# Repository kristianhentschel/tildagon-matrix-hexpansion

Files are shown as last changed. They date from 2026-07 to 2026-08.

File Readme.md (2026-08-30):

# Matrix Hexpansion

This repository contains the firmware and hardware projects for the **Matrix Hexpansion** and the CH32V006 breakout hexpansion it is based on. This is an add-on for the EMF Camp Tildagon/Spaceagon [badge](https://tildagon.badge.emfcamp.org/).

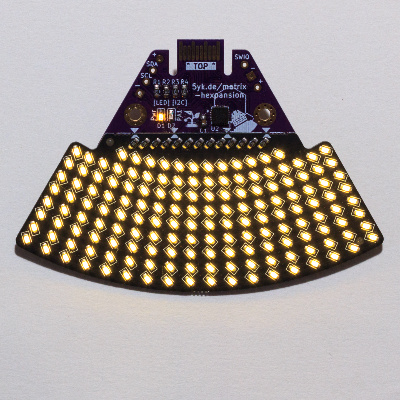
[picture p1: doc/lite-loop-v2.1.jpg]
The lite-loop LED matrix board, soldered to and placed on top of the base board. Its 156 warm-white LEDs arranged in 9 concentric arcs (1 row of 12 and 8 rows of 18) spanning 60 degrees are lit up. The hexpansion connector points to the center of the circle.


The hexpansion can be controlled with the [Matrix Hexpansion companion app](https://github.com/kristianhentschel/tildagon-matrix-hexpansion-app). The processor refreshes the LED Matrix using DMA (up to 156 LEDs with charlieplexing on its 13 available GPIO pins) and can run animated patterns or scrolling text configured by the badge over the I2C interface.

Assembled hexpansions will be available to buy from [shop.alwaysplottingsomething.com](https://shop.alwaysplottingsomething.com/category/hexpansions).

Note that the LEDs are only a single colour, and not as bright as the WS2812B/NeoPixel-style RGB LEDs seen on other hexpansions. On the other hand, you can have multiple of these plugged in without running down your battery in minutes!

## Base CH32V006 prototyping hexpansion

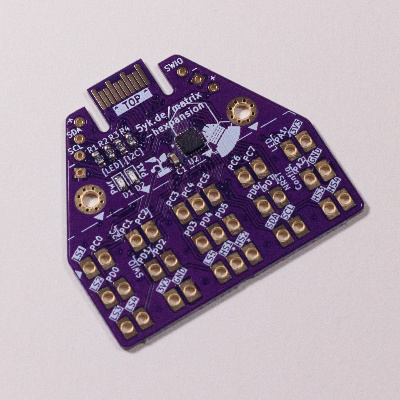
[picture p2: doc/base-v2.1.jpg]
The base board's trapezoidal top half has the hexpansion connector, a microcontroller, I2C pull-up resistors, and two status LEDs. The rectangular bottom half is a grid of three rows of rectangular pads with a large plated hole in the middle of each pad. The pads are labelled with their function in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


The common base board with the hexpansion connector must be produced with ENIG finish and holds the processor, status LEDs, configuration jumpers, and I2C pull-up resistors. It has large through hole pads for all GPIO pins and Hexpansion connector pins for a daughter board to connect to. There are also debug pads for I2C, power, and a USB programmer like the WCH LinkE.

I use the CH32V006F8U6/7 processor and program it with the [ch32fun framework](https://github.com/cnlohr/ch32fun). The CH32V003F4U6 has the same pinout and footprint, but may not have enough flash and RAM to run the matrix, control interface, and animation. If you get an assembled board from me, the processor is already programmed with a bootloader so firmware programs can be flashed from the badge without buying the dedicated USB debugger.

There is no dedicated EEPROM on the board, but the microcontroller is connected to the I2C bus and can emulate a read-only EEPROM interface if desired.

## Daughter board

Daughter boards are soldered to the base's pads, usually with SMD pads on the bottom. They can be cheaper to manufacture at low quantities (e.g. use HASL finish). The `lite-loop` board used in the Matrix Hexpansion is an example.

## Hardware

The `boards` directory contains KiCad projects and schematics for the PCBs.

* `base_v2_lite`: The base hexpansion board; with a CH32V006 co-processor and all GPIO pins and hexpansion interface pins broken out to through-hole pads.
* `lite_loop`: The 156-LED matrix display daughter board (13 pin charlie-plexing, arranged in 8 rows of 18 columns and a 9th row of 12 columns). Six instances of this make a circle surrounding the badge.

There is also a symbol library and footprints to aid in making custom daughter boards.

## Firmware

The RISC-V CH32V006 processor on the base board runs native firmware code built with the [ch32fun framework](https://github.com/cnlohr/ch32fun).

* `firmware/lite_loop` is the driver for the `lite-loop` daughter board. It maintains the LED matrix display, can run animations and scrolling text patterns, and presents an I2C interface for identifying and controlling the hexpansion from the badge.
* `firmware/bootloader_006` presents an I2C EEPROM-like interface if the `PD7` pin is pulled low during boot, so the badge can write the (non-bootloader) code flash area to replace the main program with a new firmware image.
* `firmware/blink` is a very small hello-world program that just toggles the PA1 pin attached to the status LED. It is useful when bulk provisioning or as a starting point for using the base without the lite-loop daughter board.

### Developing custom firmware

You can use the badge app to upload your own firmware program to the microcontroller on the hexpansion, for example to write your own animated patterns. To get set up you will need a few things:

1. A RISC-V toolchain, see instructions at https://github.com/cnlohr/ch32fun/wiki/Installation (building their `minichlink` and getting a USB debugger is optional as we will be using the badge to upload our firmware image).
2. A way to upload files to the badge over the USB connection, such as [mpremote](https://docs.micropython.org/en/latest/reference/mpremote.html) or [Thonny](https://thonny.org/).
3. The ["Matrix Hexpansion" app](https://apps.badge.emfcamp.org/apps/41214133), from the Tildagon app store.

Then follow these steps to upload firmware using the badge app:

1. Compile the firmware image
2. Copy the firmware image `.bin` file to the "Matrix Hexpansion" app's `assets/` folder
3. Reboop the badge
4. Open the app, and select "Firmware Upgrade", the target hexpansion slot, and your custom image.

```sh
# get the ch32fun repository
git submodule update --init --recursive

# make a copy of the lite-loop firmware to start from
cd firmware
cp -r lite_loop my_firmware

# build your firmware binary
cd my_firmware
make build

# copy the firmware image to the badge file system
mpremote cp main.bin :/apps/kristianhentschel_tildagon_matrix_hexpansion_app/assets/my_firmware.bin
```

To get started, place this code at the top of the `loop()` function in `my_firmware/main.c`:

```c
// void loop() {
  while(true) {
    for (int frame = 0; frame < 2 * LEDS_GRID_COLS; frame++) {
      for (int row = 0; row < LEDS_GRID_ROWS; row++) {
        for (int col = 0; col < LEDS_GRID_COLS; col++) {
          // Find the frame buffer index of the LED at the current row and column:
          int index = leds_grid_indices[row * LEDS_GRID_COLS + col];
          // In the array of grid indices some values are 255, because the first row only has 12 LEDs instead of 18, so skip those:
          if (index >= LEDS_COUNT) continue;
          
          // Set the LED to on or off depending on the current frame
          if (frame < LEDS_GRID_COLS) {
            frame_buffer[index] = col < frame ? 255 : 0;
          } else {
            frame_buffer[index] = col >= frame - LEDS_GRID_COLS ? 255 : 0;
          }
        }
      }

      Delay_Ms(40);
    }
  }

  // ... existing loop code, unreachable
// }
```

You may also wish to change the name in the hexpansion header; this will stop the app attempting to control it. Replace the `friendly_name` value in the hexpansion header (it must still be at most 9 characters; fill any extra slots with `0`):

```c
// static hexpansion_header_t g_hexpansion_header = {
  // ...
  // .friendly_name = {'L', 'i', 't', 'e', 'l', 'o', 'o', 'p', 0},
  .friendly_name = {'M', 'y', ' ', 'M', 'a', 't', 'r', 'i', 'x'},
// };
```

You can use the defined LED positions in [leds.h]() (using the `leds_polar_positions` and `leds_grid_indices` variables); or you could add to the list of animations, keep the name, and modify the badge app to trigger them.

Note this is all still somewhat of a prototype, for example I may change the position values to an integer representation, or come up with a system for the app to discover custom patterns to make this easier in future versions. It would also be nice to synchronise animations across multiple hexpansions.

### Bootloader and provisioning

To provision a factory-fresh processor, the bootloader must first be flashed and configured using a dedicated programmer like the WCH-LinkE and the ch32fun `minichlink` tool. We must flash the flash bootloader, configure PD7 use as GPIO rather than reset, and flash a main program. I use the `blink` program during provisioning because it is quick to build and upload; the lite_loop program is then flashed from the badge during testing. The `provision.sh` script does these steps, optionally in a loop:

```sh
./provision.sh --app blink --bootloader --loop
```
For end users, firmware updates can be applied from the badge app and a dedicated programmer is not required (but may still be helpful for debugging if writing your own firmware).

## Note on previous iteration

The base is called `v2` because the first iteration of this also had a [IS31FL3731](https://lumissil.com/assets/pdf/core/IS31FL3731_DS.pdf) LED driver, but this was found to add unnecessary cost and complexity and was never assembled or programmed properly. I suspect it would be able to drive the LED's quite a bit more brightly and consistently! In the current `v2` the current limiting resistors were moved to the daughter board and the breakout pads have a more useful generic layout, also including the hexpansion connector pins.

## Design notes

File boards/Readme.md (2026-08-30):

# Boards

* `base_v2_lite` is the base board. It has to be manufactured as a 1mm board with ENIG.
* `lite_loop` is the main "Matrix Hexpansion" LED daughter board. It can be connected to the top of the base board with solder paste and a hot air tool.

# Symbols and Footprints

* `matrix-hexpansion.kicad_sym` has schematic symbols for the base board's breakout pin array, including a version that only has the first two rows of pins as used on the `lite_loop` board.
* `matrix-hexpansion.pretty` is a footprint library including THT (used on the base) and SMD (used on the daughter boards) variations of the breakout pin array. The footprints have alignment aids on silkscreen and user layers.

# Acknowledgements

The base board is derived from the [badge-2024-hardware hexpansion template](https://github.com/emfcamp/badge-2024-hardware/tree/main/hexpansion) by kliment under CERN-OHL-P. The `hexpansion-edge-connector` symbol and footprint included with this repository for convenience are also from the same project.

# Stencils for previous version

If you want to make a stencil for your soldering kit picked up at EMF Camp 2026 (marked `v2`, `2026-05-22`), here are links to the [gerber files](https://stuff.5yk.de/20260719_lite_loop_gerber.zip) and [DXF exports](https://stuff.5yk.de/20260719_lite_loop_stencil.zip).

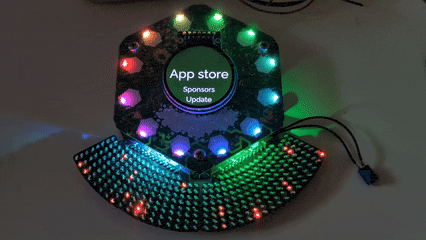
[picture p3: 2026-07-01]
doc/starfield.gif

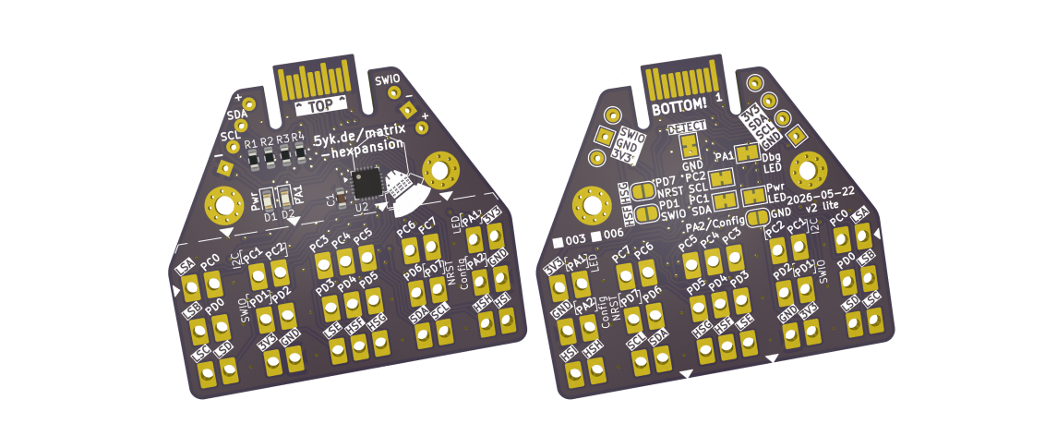
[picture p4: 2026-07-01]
doc/base-render-v2.png

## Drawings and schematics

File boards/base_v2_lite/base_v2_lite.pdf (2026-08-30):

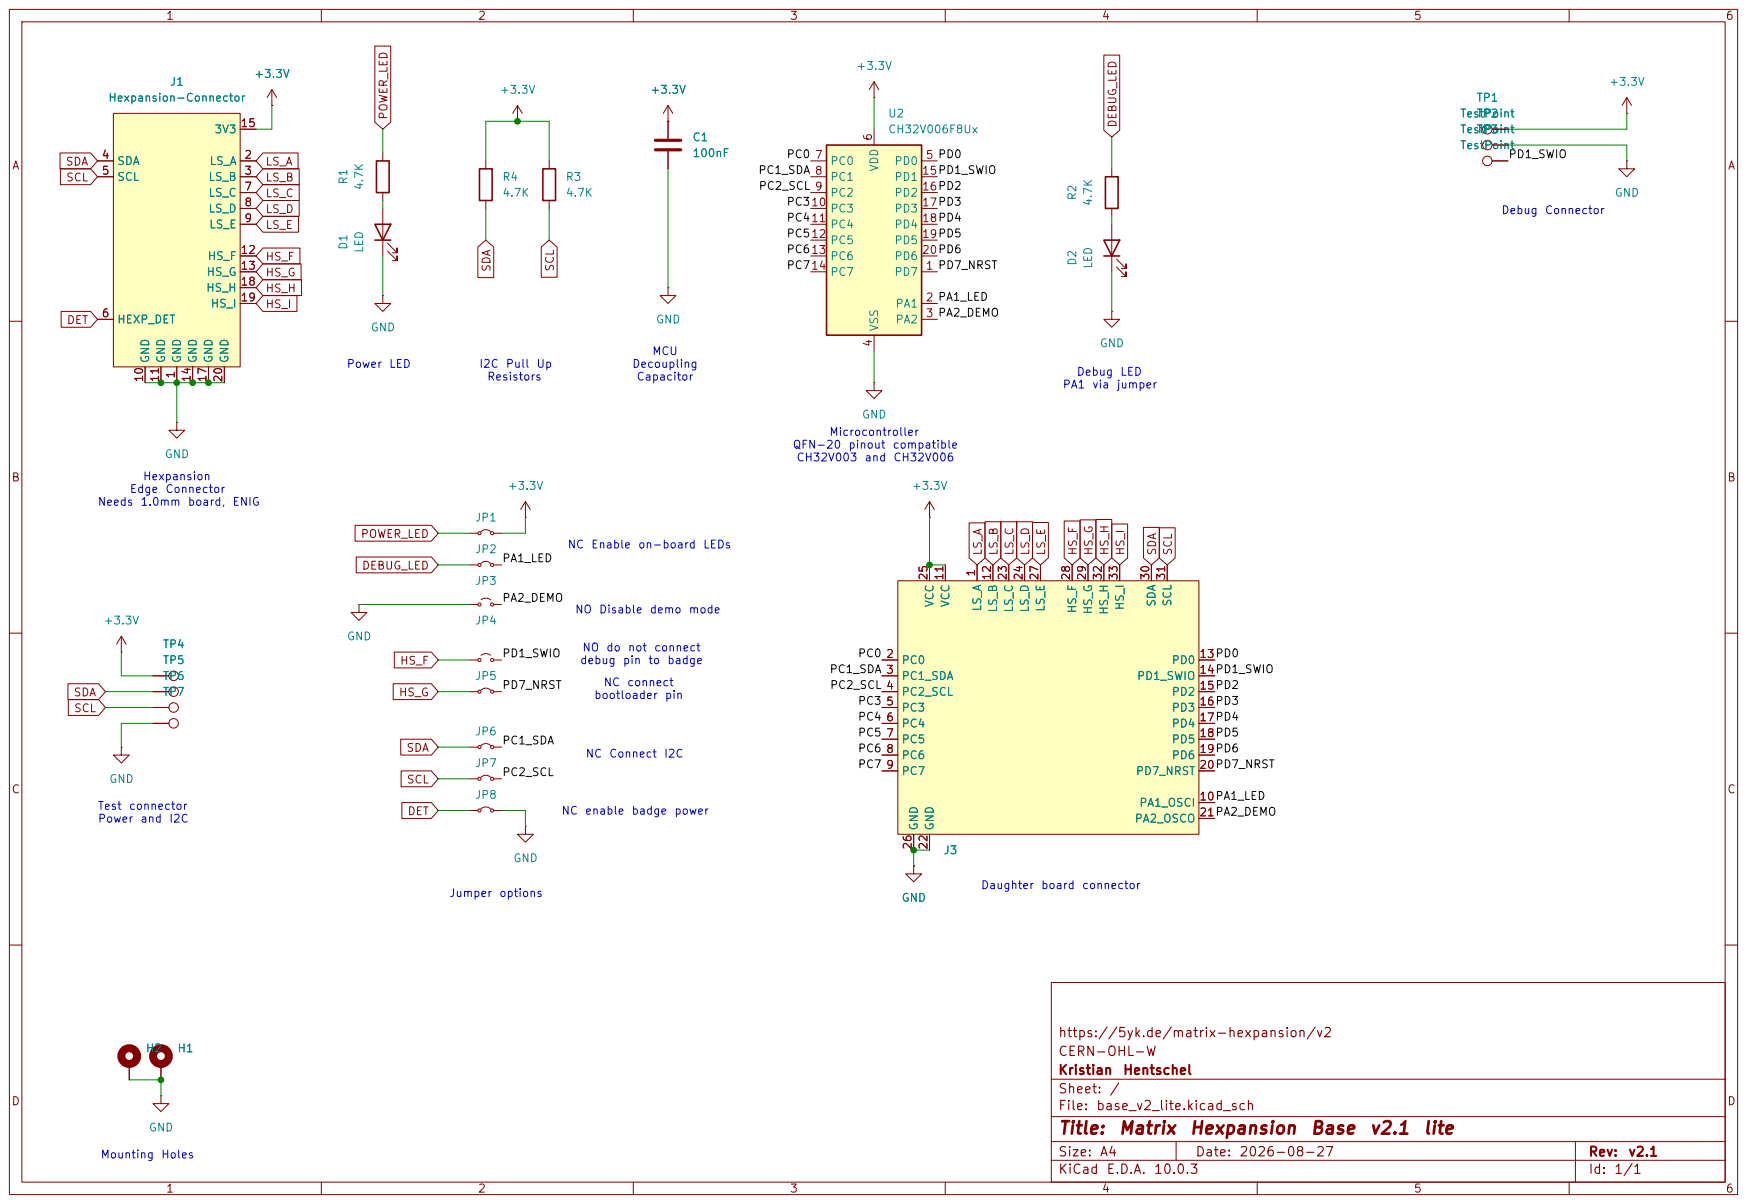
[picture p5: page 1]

Debug Connector NO Disable demo mode NC Enable on-board LEDs Hexpansion

PA1 via jumper NC Connect I2C NO do not connect debug pin to badge NC enable badge power NC connect bootloader pin Power LED

https://5yk.de/matrix-hexpansion/v2
CERN-OHL-W
Kristian Hentschel
Sheet: /
File: base_v2_lite.kicad_sch
Title: Matrix Hexpansion Base v2.1 lite

Size: A4 | Rev: v2.1
KiCad E.D.A. 10.0.3 | Id: 1/1

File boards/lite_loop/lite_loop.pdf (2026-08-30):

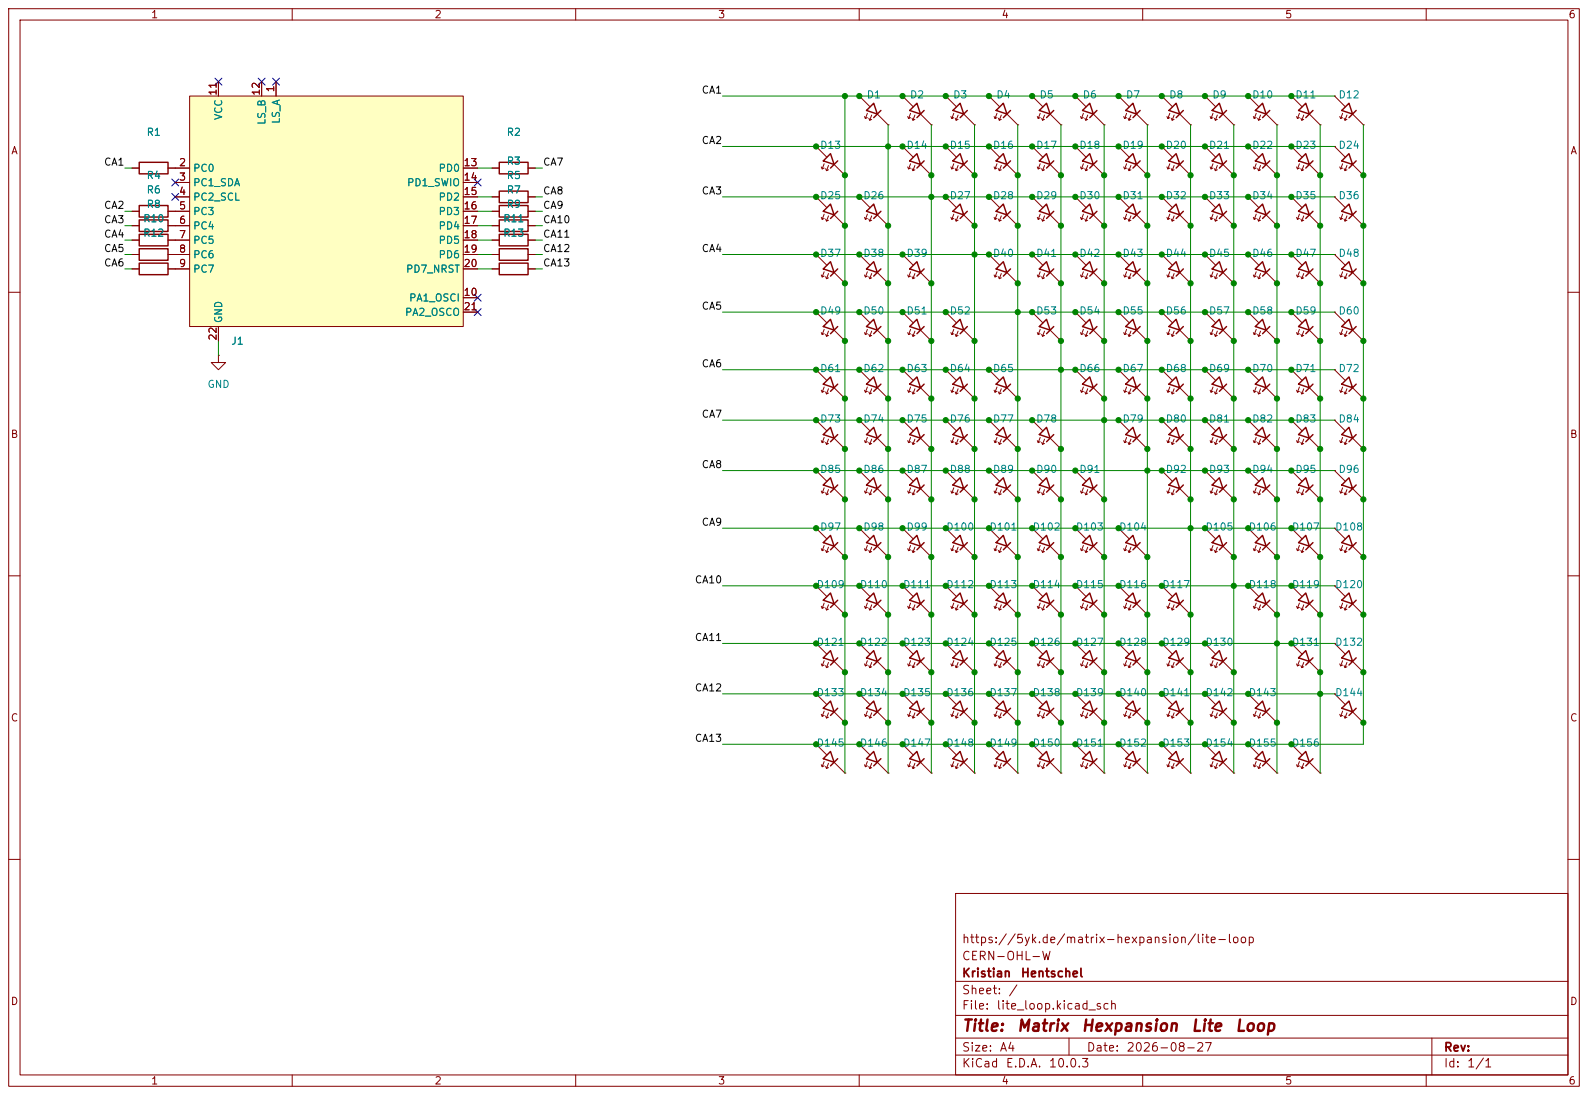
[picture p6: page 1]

https://5yk.de/matrix-hexpansion/lite-loop
CERN-OHL-W
Kristian Hentschel
Sheet: /
File: lite_loop.kicad_sch
Title: Matrix Hexpansion Lite Loop

Size: A4 | Rev:
KiCad E.D.A. 10.0.3 | Id: 1/1

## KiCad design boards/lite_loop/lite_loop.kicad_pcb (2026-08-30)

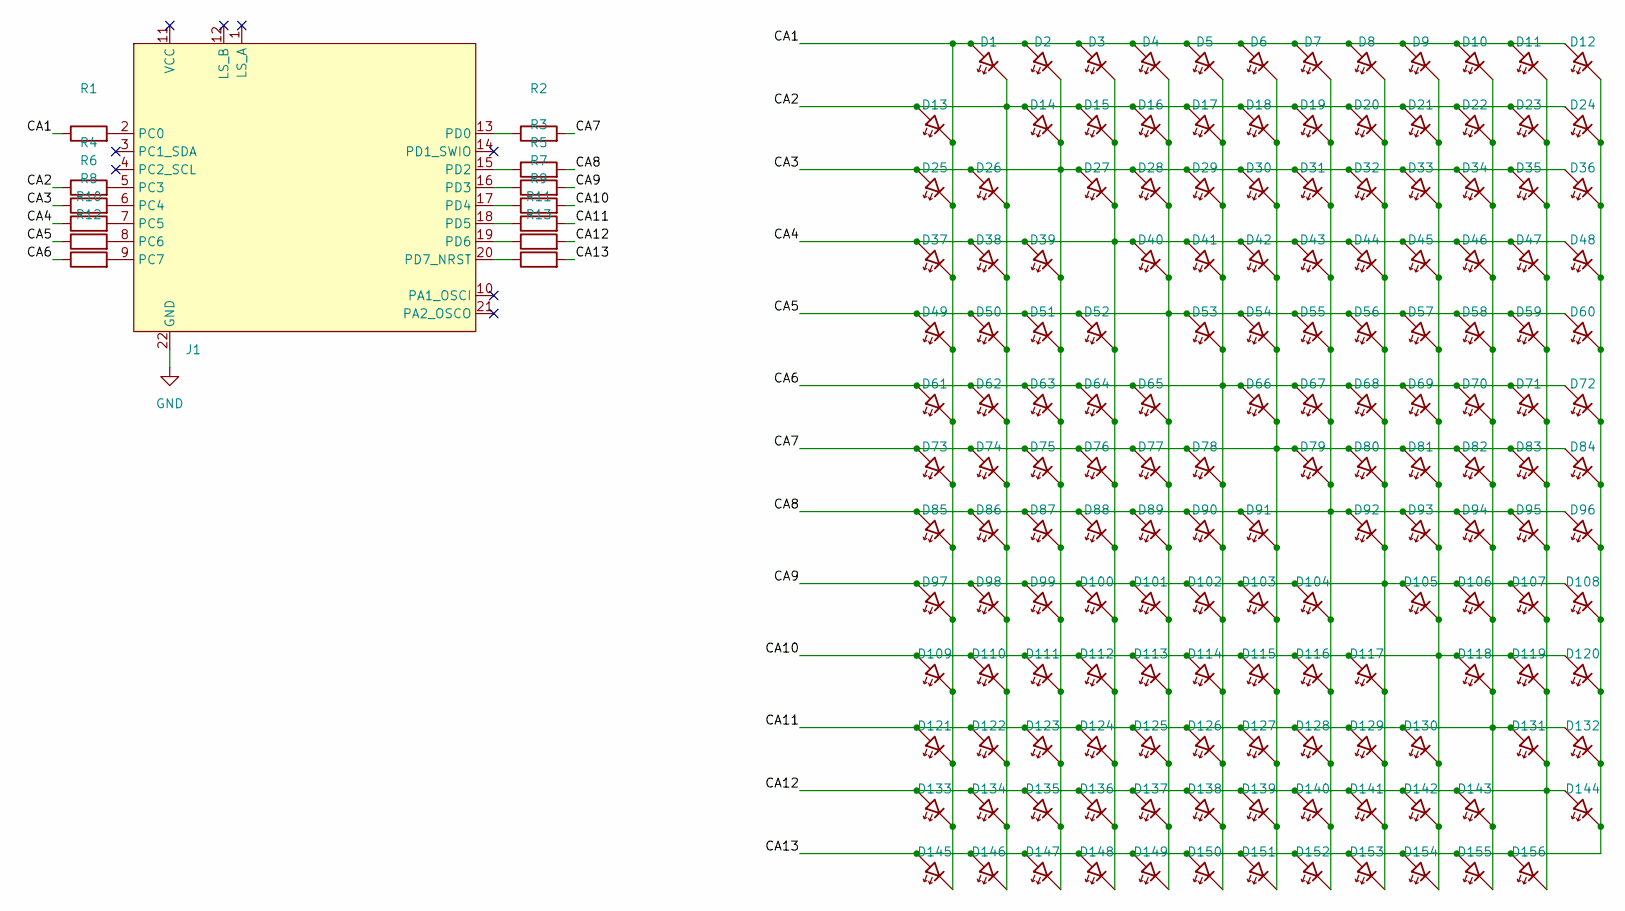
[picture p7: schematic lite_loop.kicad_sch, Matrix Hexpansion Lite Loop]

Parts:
D1, D2, D3, D4, D5, D6, D7, D8, D9, D10, D11, D12, D13, D14, D15, D16, D17, D18, D19, D20, D21, D22, D23, D24, D25, D26, D27, D28, D29, D30, D31, D32, D33, D34, D35, D36, D37, D38, D39, D40, D41, D42, D43, D44, D45, D46, D47, D48, D49, D50, D51, D52, D53, D54, D55, D56, D57, D58, D59, D60, D61, D62, D63, D64, D65, D66, D67, D68, D69, D70, D71, D72, D73, D74, D75, D76, D77, D78, D79, D80, D81, D82, D83, D84, D85, D86, D87, D88, D89, D90, D91, D92, D93, D94, D95, D96, D97, D98, D99, D100, D101, D102, D103, D104, D105, D106, D107, D108, D109, D110, D111, D112, D113, D114, D115, D116, D117, D118, D119, D120, D121, D122, D123, D124, D125, D126, D127, D128, D129, D130, D131, D132, D133, D134, D135, D136, D137, D138, D139, D140, D141, D142, D143, D144, D145, D146, D147, D148, D149, D150, D151, D152, D153, D154, D155, D156: LED; LED_0603_1608Metric
J1: matrix-hexpansion-base-v2-partial-SMD
R1, R2, R3, R4, R5, R6, R7, R8, R9, R10, R11, R12, R13: 100R; R_0603_1608Metric

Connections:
/CA1: D1.2 (A), D2.2 (A), D3.2 (A), D4.2 (A), D5.2 (A), D6.2 (A), D7.2 (A), D8.2 (A), D9.2 (A), D10.2 (A), D11.2 (A), D12.2 (A), D13.1 (K), D25.1 (K), D37.1 (K), D49.1 (K), D61.1 (K), D73.1 (K), D85.1 (K), D97.1 (K), D109.1 (K), D121.1 (K), D133.1 (K), D145.1 (K), R1.1
/CA2: D1.1 (K), D13.2 (A), D14.2 (A), D15.2 (A), D16.2 (A), D17.2 (A), D18.2 (A), D19.2 (A), D20.2 (A), D21.2 (A), D22.2 (A), D23.2 (A), D24.2 (A), D26.1 (K), D38.1 (K), D50.1 (K), D62.1 (K), D74.1 (K), D86.1 (K), D98.1 (K), D110.1 (K), D122.1 (K), D134.1 (K), D146.1 (K), R4.1
/CA3: D2.1 (K), D14.1 (K), D25.2 (A), D26.2 (A), D27.2 (A), D28.2 (A), D29.2 (A), D30.2 (A), D31.2 (A), D32.2 (A), D33.2 (A), D34.2 (A), D35.2 (A), D36.2 (A), D39.1 (K), D51.1 (K), D63.1 (K), D75.1 (K), D87.1 (K), D99.1 (K), D111.1 (K), D123.1 (K), D135.1 (K), D147.1 (K), R6.1
/CA4: D3.1 (K), D15.1 (K), D27.1 (K), D37.2 (A), D38.2 (A), D39.2 (A), D40.2 (A), D41.2 (A), D42.2 (A), D43.2 (A), D44.2 (A), D45.2 (A), D46.2 (A), D47.2 (A), D48.2 (A), D52.1 (K), D64.1 (K), D76.1 (K), D88.1 (K), D100.1 (K), D112.1 (K), D124.1 (K), D136.1 (K), D148.1 (K), R8.1
/CA5: D4.1 (K), D16.1 (K), D28.1 (K), D40.1 (K), D49.2 (A), D50.2 (A), D51.2 (A), D52.2 (A), D53.2 (A), D54.2 (A), D55.2 (A), D56.2 (A), D57.2 (A), D58.2 (A), D59.2 (A), D60.2 (A), D65.1 (K), D77.1 (K), D89.1 (K), D101.1 (K), D113.1 (K), D125.1 (K), D137.1 (K), D149.1 (K), R10.1
/CA6: D5.1 (K), D17.1 (K), D29.1 (K), D41.1 (K), D53.1 (K), D61.2 (A), D62.2 (A), D63.2 (A), D64.2 (A), D65.2 (A), D66.2 (A), D67.2 (A), D68.2 (A), D69.2 (A), D70.2 (A), D71.2 (A), D72.2 (A), D78.1 (K), D90.1 (K), D102.1 (K), D114.1 (K), D126.1 (K), D138.1 (K), D150.1 (K), R12.1
/CA7: D6.1 (K), D18.1 (K), D30.1 (K), D42.1 (K), D54.1 (K), D66.1 (K), D73.2 (A), D74.2 (A), D75.2 (A), D76.2 (A), D77.2 (A), D78.2 (A), D79.2 (A), D80.2 (A), D81.2 (A), D82.2 (A), D83.2 (A), D84.2 (A), D91.1 (K), D103.1 (K), D115.1 (K), D127.1 (K), D139.1 (K), D151.1 (K), R2.2
/CA8: D7.1 (K), D19.1 (K), D31.1 (K), D43.1 (K), D55.1 (K), D67.1 (K), D79.1 (K), D85.2 (A), D86.2 (A), D87.2 (A), D88.2 (A), D89.2 (A), D90.2 (A), D91.2 (A), D92.2 (A), D93.2 (A), D94.2 (A), D95.2 (A), D96.2 (A), D104.1 (K), D116.1 (K), D128.1 (K), D140.1 (K), D152.1 (K), R3.2
/CA9: D8.1 (K), D20.1 (K), D32.1 (K), D44.1 (K), D56.1 (K), D68.1 (K), D80.1 (K), D92.1 (K), D97.2 (A), D98.2 (A), D99.2 (A), D100.2 (A), D101.2 (A), D102.2 (A), D103.2 (A), D104.2 (A), D105.2 (A), D106.2 (A), D107.2 (A), D108.2 (A), D117.1 (K), D129.1 (K), D141.1 (K), D153.1 (K), R5.2
/CA10: D9.1 (K), D21.1 (K), D33.1 (K), D45.1 (K), D57.1 (K), D69.1 (K), D81.1 (K), D93.1 (K), D105.1 (K), D109.2 (A), D110.2 (A), D111.2 (A), D112.2 (A), D113.2 (A), D114.2 (A), D115.2 (A), D116.2 (A), D117.2 (A), D118.2 (A), D119.2 (A), D120.2 (A), D130.1 (K), D142.1 (K), D154.1 (K), R7.2
/CA11: D10.1 (K), D22.1 (K), D34.1 (K), D46.1 (K), D58.1 (K), D70.1 (K), D82.1 (K), D94.1 (K), D106.1 (K), D118.1 (K), D121.2 (A), D122.2 (A), D123.2 (A), D124.2 (A), D125.2 (A), D126.2 (A), D127.2 (A), D128.2 (A), D129.2 (A), D130.2 (A), D131.2 (A), D132.2 (A), D143.1 (K), D155.1 (K), R9.2
/CA12: D11.1 (K), D23.1 (K), D35.1 (K), D47.1 (K), D59.1 (K), D71.1 (K), D83.1 (K), D95.1 (K), D107.1 (K), D119.1 (K), D131.1 (K), D133.2 (A), D134.2 (A), D135.2 (A), D136.2 (A), D137.2 (A), D138.2 (A), D139.2 (A), D140.2 (A), D141.2 (A), D142.2 (A), D143.2 (A), D144.2 (A), D156.1 (K), R11.2
/CA13: D12.1 (K), D24.1 (K), D36.1 (K), D48.1 (K), D60.1 (K), D72.1 (K), D84.1 (K), D96.1 (K), D108.1 (K), D120.1 (K), D132.1 (K), D144.1 (K), D145.2 (A), D146.2 (A), D147.2 (A), D148.2 (A), D149.2 (A), D150.2 (A), D151.2 (A), D152.2 (A), D153.2 (A), D154.2 (A), D155.2 (A), D156.2 (A), R13.2
GND: J1.22 (GND)
unnamed: J1.2 (PC0), R1.2
unnamed: J1.5 (PC3), R4.2
unnamed: J1.6 (PC4), R6.2
unnamed: J1.7 (PC5), R8.2
unnamed: J1.8 (PC6), R10.2
unnamed: J1.9 (PC7), R12.2
unnamed: J1.13 (PD0), R2.1
unnamed: J1.15 (PD2), R3.1
unnamed: J1.16 (PD3), R5.1
unnamed: J1.17 (PD4), R7.1
unnamed: J1.18 (PD5), R9.1
unnamed: J1.19 (PD6), R11.1
unnamed: J1.20 (PD7_NRST), R13.1

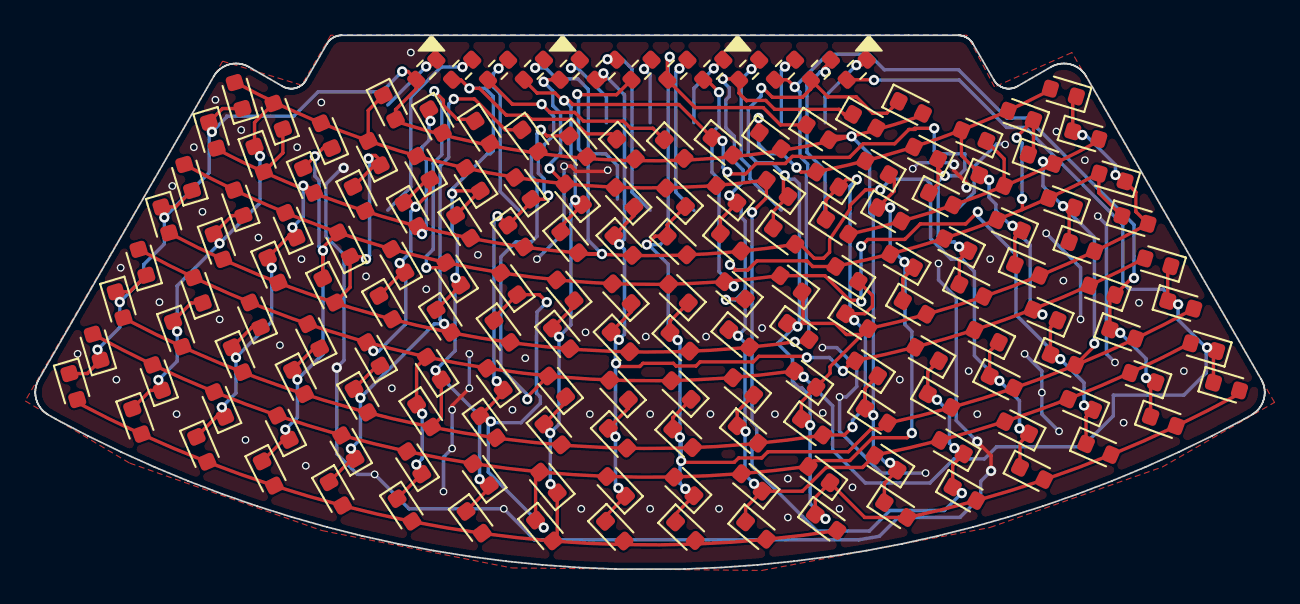
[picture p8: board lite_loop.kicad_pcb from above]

Board: 2 copper layers, 71.4 x 31.0 mm, 170 parts (0 on the bottom side), 26 nets.

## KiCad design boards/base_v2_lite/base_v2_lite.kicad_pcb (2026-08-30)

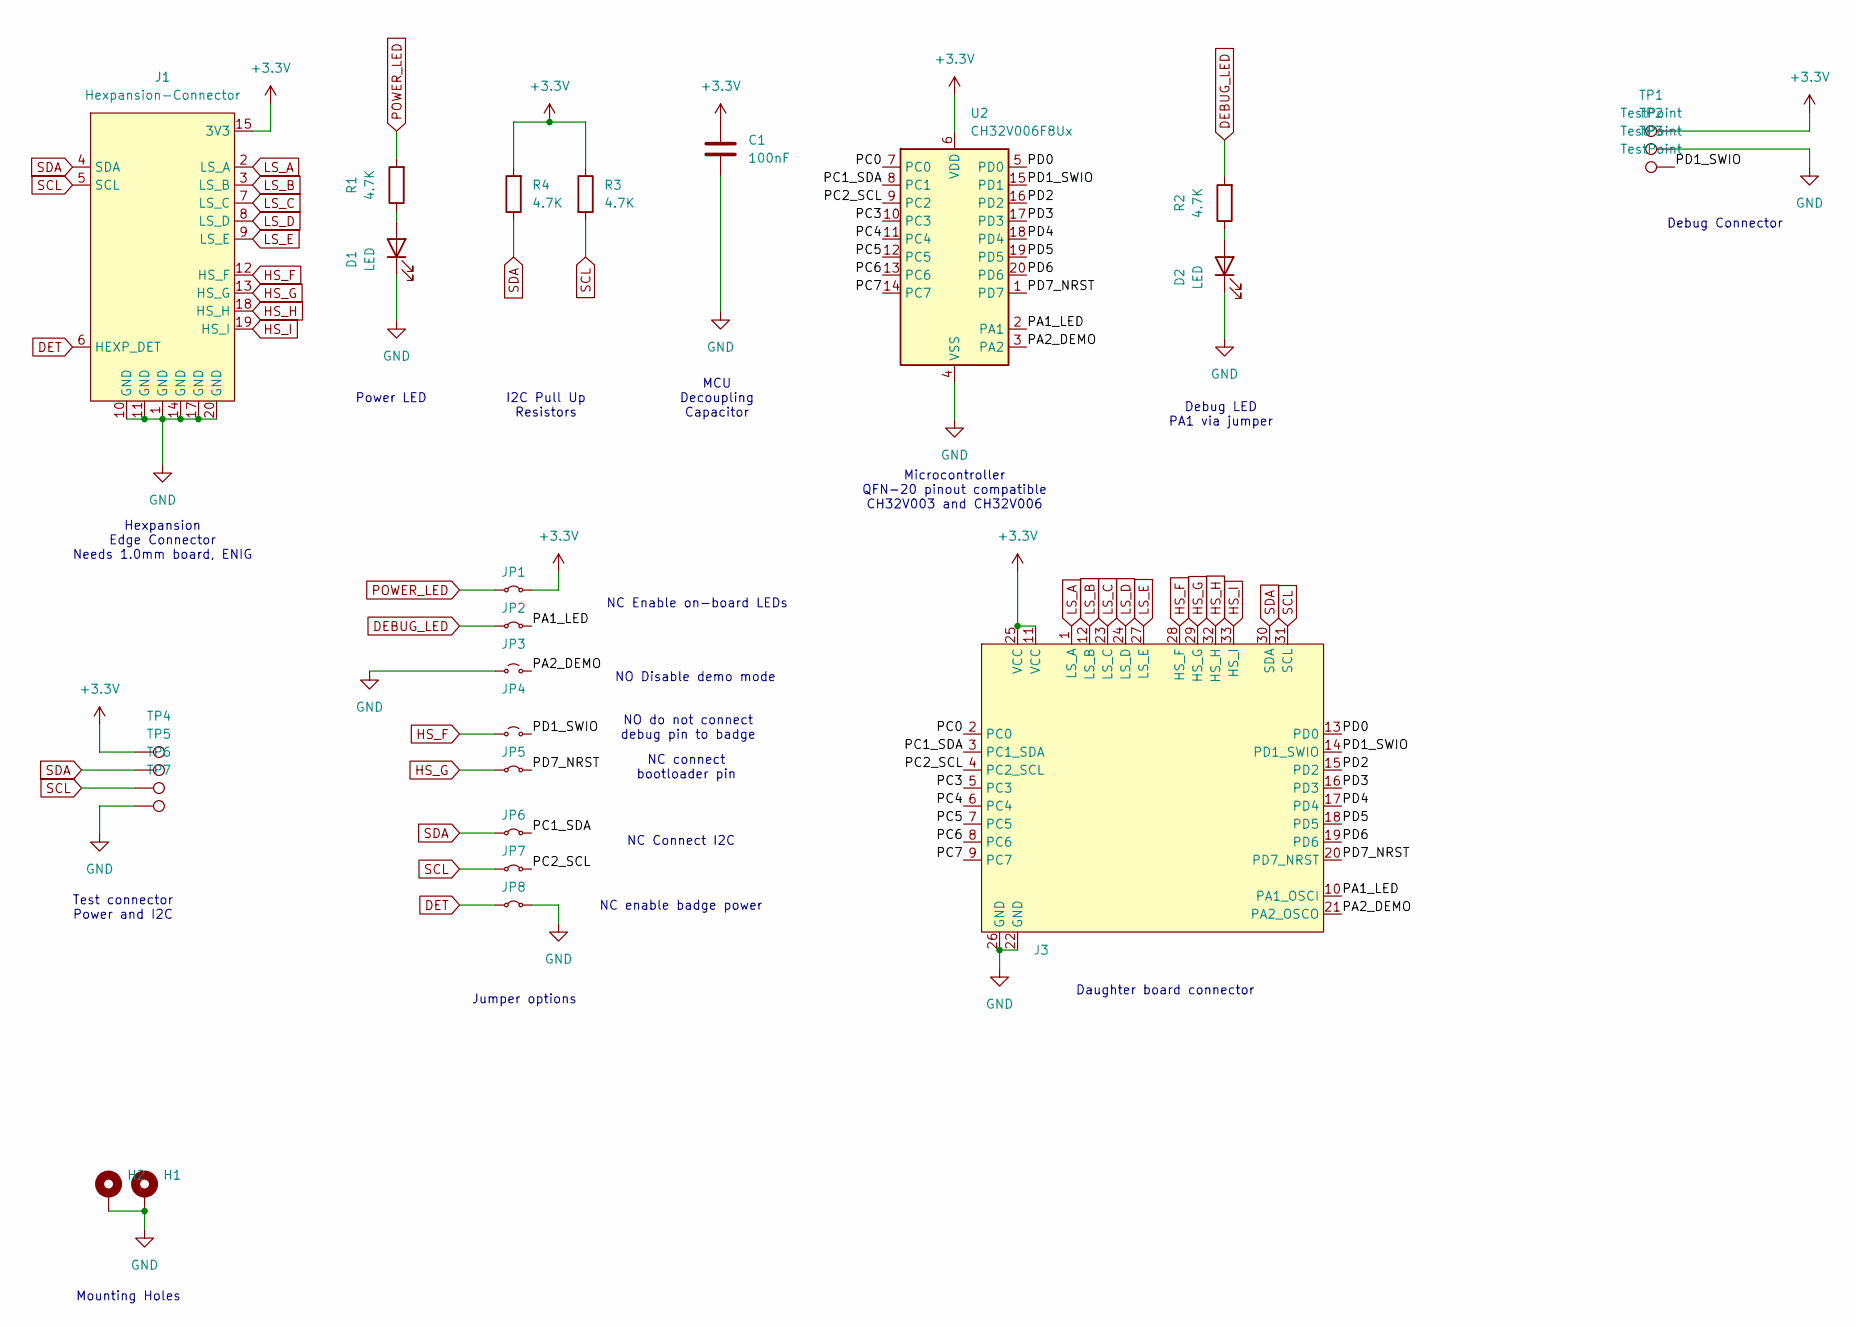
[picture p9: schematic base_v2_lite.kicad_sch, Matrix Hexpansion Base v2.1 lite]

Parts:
C1: 100nF; C_0603_1608Metric
D1, D2: LED; LED_0603_1608Metric
H1, H2: MountingHole_Pad; MountingHole_2.2mm_M2_Pad_Via
J1: Hexpansion-Connector; hexpansion-edge-connector
J3: matrix-hexpansion-base-v2-THT
JP1, JP2, JP5, JP6, JP7, JP8: Jumper_2_Small_Bridged; SolderJumper-2_P1.3mm_Bridged_Pad1.0x1.5mm
JP3, JP4: Jumper_2_Small_Open; SolderJumper-2_P1.3mm_Open_RoundedPad1.0x1.5mm
R1, R2, R3, R4: 4.7K; R_0603_1608Metric
TP1, TP3, TP4, TP5, TP6: TestPoint; TestPoint_THTPad_D1.5mm_Drill0.7mm
TP2, TP7: TestPoint; TestPoint_THTPad_1.5x1.5mm_Drill0.7mm
U2: CH32V006F8Ux; QFN-20-1EP_3x3mm_P0.4mm_EP1.65x1.65mm

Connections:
+3.3V: C1.1, J1.15 (3V3), J1.16 (3V3), J3.11 (VCC), J3.25 (VCC), JP1.2 (B), R3.1, R4.2, TP1.1 (1_1), TP4.1 (1_1), U2.6 (VDD)
/PA1_LED: J3.10 (PA1_OSCI), JP2.2 (B), U2.2 (PA1)
/PA2_DEMO: J3.21 (PA2_OSCO), JP3.2 (B), U2.3 (PA2)
/PC0: J3.2 (PC0), U2.7 (PC0)
/PC1_SDA: J3.3 (PC1_SDA), JP6.2 (B), U2.8 (PC1)
/PC2_SCL: J3.4 (PC2_SCL), JP7.2 (B), U2.9 (PC2)
/PC3: J3.5 (PC3), U2.10 (PC3)
/PC4: J3.6 (PC4), U2.11 (PC4)
/PC5: J3.7 (PC5), U2.12 (PC5)
/PC6: J3.8 (PC6), U2.13 (PC6)
/PC7: J3.9 (PC7), U2.14 (PC7)
/PD0: J3.13 (PD0), U2.5 (PD0)
/PD1_SWIO: J3.14 (PD1_SWIO), JP4.2 (B), TP3.1 (1_1), U2.15 (PD1)
/PD2: J3.15 (PD2), U2.16 (PD2)
/PD3: J3.16 (PD3), U2.17 (PD3)
/PD4: J3.17 (PD4), U2.18 (PD4)
/PD5: J3.18 (PD5), U2.19 (PD5)
/PD6: J3.19 (PD6), U2.20 (PD6)
/PD7_NRST: J3.20 (PD7_NRST), JP5.2 (B), U2.1 (PD7)
DEBUG_LED: JP2.1 (A), R2.2
DET: J1.6 (HEXP_DET), JP8.1 (A)
GND: C1.2, D1.1 (K), D2.1 (K), H1.1 (1_1), H2.1 (1_1), J1.1 (GND), J1.10 (GND), J1.11 (GND), J1.14 (GND), J1.17 (GND), J1.20 (GND), J3.22 (GND), J3.26 (GND), JP3.1 (A), JP8.2 (B), TP2.1 (1_1), TP7.1 (1_1), U2.4 (VSS), U2.21 (VSS)
HS_F: J1.12 (HS_F), J3.28 (HS_F), JP4.1 (A)
HS_G: J1.13 (HS_G), J3.29 (HS_G), JP5.1 (A)
HS_H: J1.18 (HS_H), J3.32 (HS_H)
HS_I: J1.19 (HS_I), J3.33 (HS_I)
LS_A: J1.2 (LS_A), J3.1 (LS_A)
LS_B: J1.3 (LS_B), J3.12 (LS_B)
LS_C: J1.7 (LS_C), J3.23 (LS_C)
LS_D: J1.8 (LS_D), J3.24 (LS_D)
LS_E: J1.9 (LS_E), J3.27 (LS_E)
unnamed: D1.2 (A), R1.1
unnamed: D2.2 (A), R2.1
POWER_LED: JP1.1 (A), R1.2
SCL: J1.5 (SCL), J3.31 (SCL), JP7.1 (A), R3.2, TP6.1 (1_1)
SDA: J1.4 (SDA), J3.30 (SDA), JP6.1 (A), R4.1, TP5.1 (1_1)

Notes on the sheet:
Hexpansion Edge Connector Needs 1.0mm board, ENIG
Mounting Holes
NO Disable demo mode
NC Enable on-board LEDs
MCU Decoupling Capacitor
Test connector Power and I2C
NC connect bootloader pin
Microcontroller QFN-20 pinout compatible CH32V003 and CH32V006
Debug LED PA1 via jumper
NC enable badge power
I2C Pull Up Resistors
Jumper options
Power LED
Daughter board connector
Debug Connector
NO do not connect debug pin to badge
NC Connect I2C

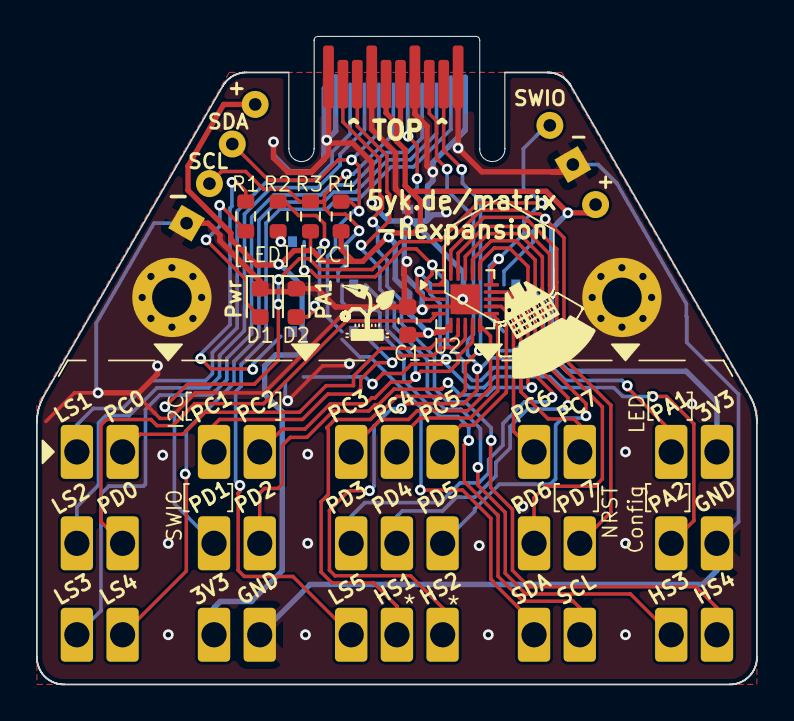
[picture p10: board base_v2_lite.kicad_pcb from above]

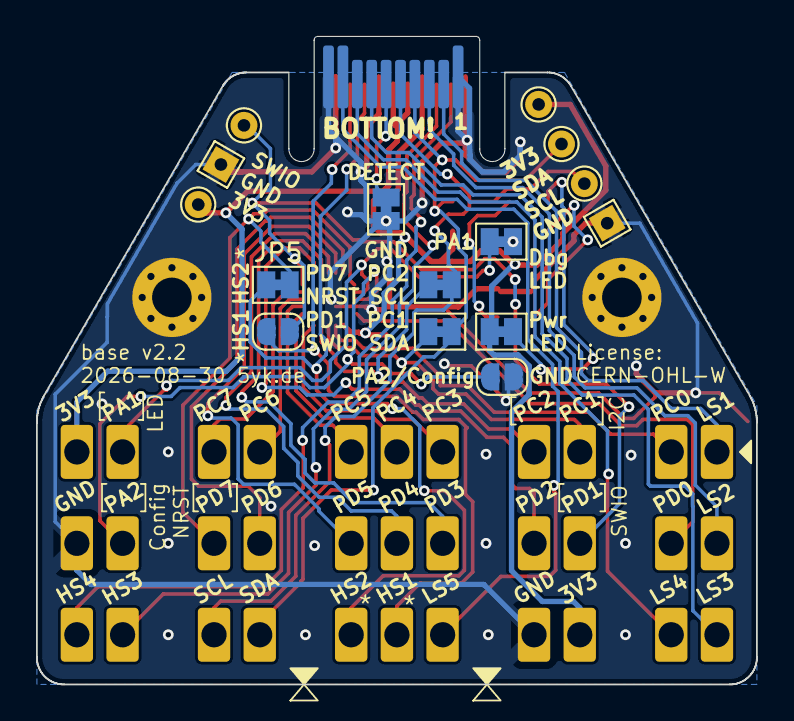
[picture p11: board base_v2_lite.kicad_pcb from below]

Board: 2 copper layers, 40.0 x 36.0 mm, 27 parts (15 on the bottom side), 36 nets.

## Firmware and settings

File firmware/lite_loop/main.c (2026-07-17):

#include "ch32fun.h"
#include <stdio.h>
#include "../shared/matrix.h"
#include "../shared/debug_printf.h"
#include "../shared/hexpansion_header.h"
#include "../shared/i2c_again.h"
#include "../shared/core_registers.h"
#include "leds.h"
#include "animations/level.h"
#include "animations/starfield.h"
#include "animations/text.h"

// #define DEBUG_BLINK

void loop() __attribute__((section(".srodata")));

uint32_t count;
matrix_pwm_t frame_buffer[MATRIX_NUM_LEDS];

static hexpansion_header_t g_hexpansion_header = {
  .magic = {'T', 'H', 'E', 'X'},
  .manifest_version = {'2', '0', '2', '4'},
  .filesystem_info = {
    .offset = 32, // offset from start of eeprom, must be multiple of page size
    .page_size = 32, // emulated eeprom page size (not littlefs block size I think)
    .total_size = 0, // emulated space, reads past fs will return zero
  },
  .vendor_id = 0xCAFE, // "misc hexpansions" from https://badge.emfcamp.org/Tildagon/UHB-IF/Uncontrolled_IDs
  .product_id = 0x54E1,
  .unique_id = 0x0000,
  .friendly_name = {'L', 'i', 't', 'e', 'l', 'o', 'o', 'p', 0},
};

volatile core_registers_t g_core_registers = {
  .core_registers_version = CORE_REGISTERS_VERSION,
};
i2c_page_definition_t g_page_definitions[] = {
  {.page_address = 0, .data = (uint8_t *)&g_core_registers, .data_size = sizeof(g_core_registers)},
};

static const i2c_config_t g_i2c_config = {
  .primary_address = 0x20,
  .primary_num_pages = 1,
  .primary_page_definitions = g_page_definitions,

  .secondary_address = 0x50, // EEPROM on 0x50 (expected fixed address by companion app)
  .secondary_header =  &g_hexpansion_header,
  .secondary_fs = NULL,
  .secondary_fs_size = 0,
};

int main()
{
  SystemInit();
  Delay_Ms(50);

  funGpioInitAll();
  funPinMode(PA1, FUN_OUTPUT);
  funPinMode(PC1, GPIO_CFGLR_OUT_10Mhz_AF_OD); // SDA
  funPinMode(PC2, GPIO_CFGLR_OUT_10Mhz_AF_OD); // SCL

  funDigitalWrite(PA1, FUN_LOW);

  g_hexpansion_header.unique_id = ESIG->UNIID1 ^ ESIG->UNIID2 ^ ESIG->UNIID3 & 0xFFFF;
  hexpansion_header_fill_checksum(&g_hexpansion_header);

  i2c_setup(&g_i2c_config);

  matrix_setup(frame_buffer);

  g_core_registers.animation_type = 2;
  loop();
}

void loop() {
  int i = 0;
  while(1) {
    if (g_core_registers.direct_control_options != 0) {
      switch (g_core_registers.direct_control_options & CORE_REGISTERS_DIRECT_CONTROL_TYPE) {
        case CORE_REGISTERS_DIRECT_CONTROL_TYPE_CONST:
          // Constant mode: all LEDs set to the same PWM value (that of the first byte)
          for (uint8_t j = 0; j < MATRIX_NUM_LEDS; j++) {
            frame_buffer[j] = g_core_registers.direct_control_data[0];
          }
          break;
        case CORE_REGISTERS_DIRECT_CONTROL_TYPE_BIT:
          // Bit mode: unpack each bit in a 20 byte array to turn one LED fully on or off
          for (uint8_t j = 0; j < 20; j++) {
            for (uint8_t k = 0; k < 8; k++) {
              if (j * 8 + k < MATRIX_NUM_LEDS) {
                frame_buffer[j * 8 + k] = (g_core_registers.direct_control_data[j] & (0x01 << (7 - k))) ? 255 : 0;
              }
            }
          }
          break;
        case CORE_REGISTERS_DIRECT_CONTROL_TYPE_BYTE:
          // Byte morde: each settings byte controls the PWM level of one LED (1:1 mapping)
          for (uint8_t j = 0; j < MATRIX_NUM_LEDS; j++) {
            frame_buffer[j] = g_core_registers.direct_control_data[j];
          }
          break;
      }
    } else if (g_core_registers.animation_type == 1) {
      animation_level(&g_core_registers, frame_buffer);
    } else if (g_core_registers.animation_type == 2) {
      animation_starfield(&g_core_registers, frame_buffer);
    } else if (g_core_registers.animation_type == 3) {
      animation_text(&g_core_registers, frame_buffer);
    } else {
      // default test pattern (fill in wiring order)
      for (uint8_t j = 0; j < MATRIX_NUM_LEDS; j++) {
        frame_buffer[j] = j < i ? 255 : 4;
      }

      i = (i + 1) % (MATRIX_NUM_LEDS + 1);
      Delay_Ms(16);
      if (i == 0) {
        Delay_Ms(500);
      }
    }

    // Liveness indicator
    #ifdef DEBUG_BLINK
    static uint32_t _last_blink_tick = 0;
    if (TimeElapsed32u(SysTick->CNT, _last_blink_tick) > Ticks_from_Ms(100)) {
      funDigitalWrite(PA1, !funDigitalRead(PA1));
      _last_blink_tick = SysTick->CNT;
    }
    #endif
  }
}

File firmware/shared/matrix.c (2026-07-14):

#include "./matrix.h"

// DMA and timer configuration based on the ch32fun dma_gpio example.

volatile const uint8_t MATRIX_GPIOC_PINS[MATRIX_NUM_GPIOC_PINS] = { 
  MATRIX_GPIOC_0,
  MATRIX_GPIOC_1,
  MATRIX_GPIOC_2,
  MATRIX_GPIOC_3,
  #ifdef MATRIX_GPIOC_4
  MATRIX_GPIOC_4,
  #endif
  #ifdef MATRIX_GPIOC_5
  MATRIX_GPIOC_5,
  #endif
  #ifdef MATRIX_GPIOC_6
  MATRIX_GPIOC_6,
  #endif
  #ifdef MATRIX_GPIOC_7
  MATRIX_GPIOC_7,
  #endif
};
volatile const uint8_t MATRIX_GPIOD_PINS[MATRIX_NUM_GPIOD_PINS] = {
  MATRIX_GPIOD_0,
  MATRIX_GPIOD_1,
  MATRIX_GPIOD_2,
  MATRIX_GPIOD_3,
  #ifdef MATRIX_GPIOD_4
  MATRIX_GPIOD_4,
  #endif
  #ifdef MATRIX_GPIOD_5
  MATRIX_GPIOD_5,
  #endif
  #ifdef MATRIX_GPIOD_6
  MATRIX_GPIOD_6,
  #endif
  #ifdef MATRIX_GPIOD_7
  MATRIX_GPIOD_7,
  #endif
};

// Reference to the currently active frame buffer, expected to hold a PWM value for each LED.
static volatile matrix_pwm_t *current_frame_buffer = 0;
static volatile matrix_pwm_t *next_frame_buffer = 0;
static volatile uint8_t buffer_swap_flag = 0;

// Define buffers to hold the PWM signals to output to the GPIO ports
#define BUF_SIZE MATRIX_BUF_SIZE
#define HALF_BUF_SIZE (BUF_SIZE / 2)

static volatile uint8_t PWM_BUF_GPIOC[BUF_SIZE];
static volatile uint8_t PWM_BUF_GPIOD[BUF_SIZE];

// For each column, for each row pin, store the index into the frame buffer
#ifdef MATRIX_INDEPENDENT_PORTS
  static volatile uint8_t ROWS_GPIOC[MATRIX_NUM_GPIOC_PINS][MATRIX_NUM_GPIOC_PINS];
  static volatile uint8_t ROWS_GPIOD[MATRIX_NUM_GPIOD_PINS][MATRIX_NUM_GPIOD_PINS];
#else
  static volatile uint8_t ROWS_GPIOC[MATRIX_NUM_PINS][MATRIX_NUM_GPIOC_PINS];
  static volatile uint8_t ROWS_GPIOD[MATRIX_NUM_PINS][MATRIX_NUM_GPIOD_PINS];
#endif

#ifdef MATRIX_EXTRA_LED_GPIOD
  // Holds the frame buffer index for the extra LED
  static volatile uint8_t EXTRA_GPIOD;
#endif

static volatile uint32_t RESET_GPIOC_CFGLR;
static volatile uint32_t RESET_GPIOD_CFGLR;

void matrix_setup(volatile matrix_pwm_t *frame_buffer) {
  // Keep a reference to the current frame buffer
  if (current_frame_buffer != 0) {
    // already initialised
    matrix_swap_buffer(frame_buffer);
    return;
  } else {
    matrix_swap_buffer(frame_buffer);
  }

  #ifdef MATRIX_INDEPENDENT_PORTS
    // #define DEBUG_POSITIONS
    uint8_t frame_buffer_index = 0;

    for (uint8_t col = 0; col < MATRIX_NUM_GPIOC_PINS; col++) {
      for (uint8_t row = 0; row < MATRIX_NUM_GPIOC_PINS; row++) {
        if (frame_buffer_index >= MATRIX_NUM_LEDS) {
          break;
        }
        ROWS_GPIOC[col][row] = frame_buffer_index;

        // Only increment the index if there can be an LED at the col/row position.
        // NB this means the column pins will get assigned the value of the next LED here,
        // but will be overwritten by its correct use as a column pin in the buffer update.
        if (row != col) {
          frame_buffer_index++;
        }
      }
    }

    for (uint8_t col = 0; col < MATRIX_NUM_GPIOD_PINS; col++) {
      for (uint8_t row = 0; row < MATRIX_NUM_GPIOD_PINS; row++) {
        if (frame_buffer_index >= MATRIX_NUM_LEDS) {
          break;
        }
        ROWS_GPIOD[col][row] = frame_buffer_index;

        if (row != col) {
          frame_buffer_index++;
        }
      }
    }
  #else
    uint8_t frame_buffer_index = 0;
    for (uint8_t col = 0; col < MATRIX_NUM_PINS; col++) {
      for (uint8_t row = 0; row < MATRIX_NUM_PINS; row++) {
        if (frame_buffer_index >= MATRIX_NUM_LEDS) {
          break;
        }
        if (row < MATRIX_NUM_GPIOC_PINS) {
          ROWS_GPIOC[col][row] = frame_buffer_index;
        } else {
          ROWS_GPIOD[col][row - MATRIX_NUM_GPIOC_PINS] = frame_buffer_index;
        }

        // Only increment the index if there can be an LED at the col/row position.
        // NB this means the row for will get assigned the value of the next LED here,
        // but will be overwritten by its correct use as a column pin in the buffer update.
        if (row != col) {
          frame_buffer_index++;
        }
      }
    }
  #endif

  #ifdef MATRIX_EXTRA_LED_GPIOD
    if (frame_buffer_index < MATRIX_NUM_LEDS) {
      EXTRA_GPIOD = inverted_matrix_leds[frame_buffer_index];
      frame_buffer_index++;
    } else {
      EXTRA_GPIOD = 0; // NB this should not happen, but need to protect against overflow
    }
  #endif

  // Enable DMA peripheral
	RCC->AHBPCENR |= RCC_AHBPeriph_SRAM | RCC_AHBPeriph_DMA1;

	// Enable GPIOC, GPIOD and Timer 1 peripherals
	RCC->APB2PCENR |= RCC_APB2Periph_GPIOD | RCC_APB2Periph_GPIOC | RCC_APB2Periph_TIM1;

  // Configure all used pins as open drain outputs; the active column pin will be
  // set as a Push-Pull output later.
  // Port C
  RESET_GPIOC_CFGLR = GPIOC->CFGLR;
  for (int i = 0; i < MATRIX_NUM_GPIOC_PINS; i++) {
    uint8_t pin = MATRIX_GPIOC_PINS[i];
    
    // Clear CNF and MODE bits for the current pin
    RESET_GPIOC_CFGLR &= ~((GPIO_CFGLR_CNF0 | GPIO_CFGLR_MODE0) << 4 * pin);
    
    // Set CNF and MODE bits to the config for 10MHz open-drain output
    RESET_GPIOC_CFGLR |= GPIO_CFGLR_OUT_10Mhz_OD << 4 * pin;
  }
  GPIOC->CFGLR = RESET_GPIOC_CFGLR;
  GPIOC->OUTDR = 0xff;

  // Same for Port D
  RESET_GPIOD_CFGLR = GPIOC->CFGLR;
  for (int i = 0; i < MATRIX_NUM_GPIOD_PINS; i++) {
    uint8_t pin = MATRIX_GPIOD_PINS[i];
    RESET_GPIOD_CFGLR &= ~((GPIO_CFGLR_CNF0 | GPIO_CFGLR_MODE0) << 4 * pin);
    RESET_GPIOD_CFGLR |= GPIO_CFGLR_OUT_10Mhz_OD << 4 * pin;
  }
  
  // Optional extra LED initially also configured as OD
  #ifdef MATRIX_EXTRA_LED_GPIOD
  {
    uint8_t pin = MATRIX_EXTRA_LED_GPIOD;
    RESET_GPIOD_CFGLR &= ~((GPIO_CFGLR_CNF0 | GPIO_CFGLR_MODE0) << 4 * pin);
    RESET_GPIOD_CFGLR |= GPIO_CFGLR_OUT_10Mhz_OD << 4 * pin;
  }
  #endif
  
  GPIOD->CFGLR = RESET_GPIOD_CFGLR;
  GPIOD->OUTDR = 0xff;

  // Configure the DMA peripheral to use Channel 2 to output to GPIOC
  DMA1_Channel2->MADDR = (uint32_t) &PWM_BUF_GPIOC[0];
  DMA1_Channel2->PADDR = (uint32_t) &GPIOC->OUTDR;
  DMA1_Channel2->CNTR = MATRIX_PWM_COUNT;

  DMA1_Channel2->CFGR =
    DMA_DIR_PeripheralDST |
    DMA_Priority_High |
    DMA_MemoryDataSize_Byte |
    DMA_PeripheralDataSize_Byte |
    DMA_MemoryInc_Enable |
    DMA_PeripheralInc_Disable |
    DMA_Mode_Circular |
    DMA_CFGR3_HTIE |
    DMA_CFGR3_TCIE;

  NVIC_EnableIRQ(DMA1_Channel2_IRQn);
  DMA1_Channel2->CFGR |= DMA_CFGR2_EN;

  // Same for DMA Channel 3 to output to GPIOD
  DMA1_Channel3->MADDR = (uint32_t) &PWM_BUF_GPIOD[0];
  DMA1_Channel3->PADDR = (uint32_t) &GPIOD->OUTDR;
  DMA1_Channel3->CNTR = MATRIX_PWM_COUNT;

  DMA1_Channel3->CFGR =
    DMA_DIR_PeripheralDST |
    DMA_Priority_High |
    DMA_MemoryDataSize_Byte |
    DMA_PeripheralDataSize_Byte |
    DMA_MemoryInc_Enable |
    DMA_PeripheralInc_Disable |
    DMA_Mode_Circular;
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

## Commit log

2026-07-03 Change PID, bootloader blink pin, and check bootloader pin instead of always entering it
2026-07-11 Text mode, two fixed-width fonts, offset set in registers
    [main.c]
2026-07-14 Always read the I2C DATAR to avoid bug where we get stuck in an infinite RXNE loop (maybe due to write target getting optimized out?)
    [i2c_again.c]
2026-07-14 Fix bootloader timeout so it actually stays in bootloader for a few seconds
    [bootloader.c]
2026-07-16 reset programming state after address write, only erase if it is a programming operation
    [bootloader.c]
2026-07-19 Add temporary links to stencils and gerber files
2026-08-30 Publish KiCad projects (#1)
    * Add KiCad project for base board, as well as symbols and footprints
    * Add lite_loop board KiCad project
    * Add PDF schematics and update readme
    * Update boards section in top-level readme
    * Replace base symbol after library renames
    * Add programming tutorial, shop link, and new images to Readme
    * Remove KiKit markers, add license to base silkscreen
    [base_v2_lite.kicad_pcb, base_v2_lite.kicad_sch, lite_loop.kicad_pcb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]
